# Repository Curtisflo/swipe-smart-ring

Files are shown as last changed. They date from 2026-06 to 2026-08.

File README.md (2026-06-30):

# Swipe Smart Ring — Ring PCB

The main board for a BLE smart ring with IMU-based gesture input and capacitive
touch. This repo contains the **ring board** KiCad project: PCB layout,
schematic, and the custom footprints used by both.

**Status:** prototype, not yet fabricated or tested. Routed and verified in
KiCad 9 — **DRC clean: 0 errors, 0 warnings, 0 unconnected nets.**

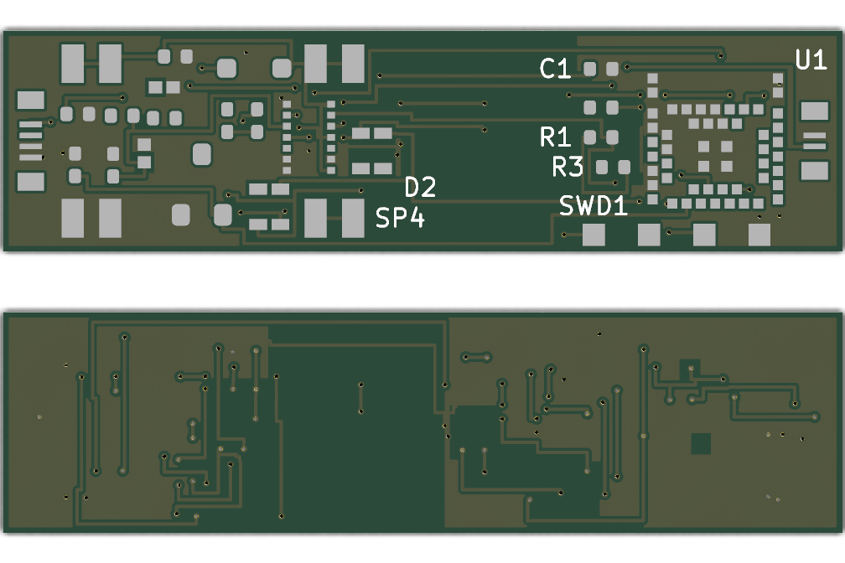
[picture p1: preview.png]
Ring board, top and bottom


It's small — the board outline is **38 × 10 mm** (about the footprint of a
stick of gum).

The board isn't meant to stay flat. The middle 8 mm is a **flex** section: the
rigid signet and BLE ends fold relative to each other there, so the board follows
the curve of the finger inside the housing. In the housing the BLE end sits
**115°** around the ring from the signet, and the rigid ends stay flat — so the
8 mm flex takes that whole ~115° bend (about a 4 mm radius, well inside the
material's 0.6 mm minimum).

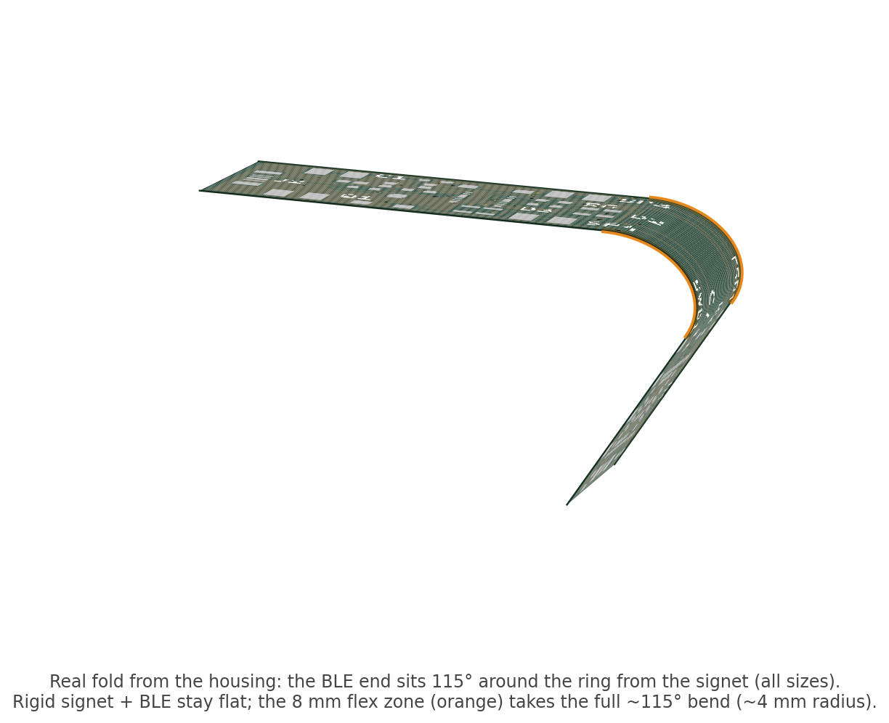
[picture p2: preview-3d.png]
Rigid-flex bend at the flex zone


A note on the rigid-flex: the flex zone is captured here as **design intent** —
the layout is zoned signet (18 mm) / flex (8 mm) / BLE (12 mm) along the board's
length, with the bend taken by the middle 8 mm. The `ring.kicad_pcb` itself is a
flat 2-layer prototype; the actual rigid-flex **stackup and coverlay callouts are
left to the fabricator**.

## What this is

A 2-layer **rigid-flex** board that wraps around a finger. It carries a Nordic
nRF52832 BLE SoC, a 6-axis IMU with built-in capacitive (Qvar) touch sensing, a
haptic motor driver, indicator LEDs, and the spring contacts / connectors that
mate with the ring housing.

The board is split into three zones along its length:

```
[ signet  18mm rigid ] —— [ flex 8mm ] —— [ BLE 12mm rigid ]
  battery + motor +                          ANNA-B112 module +
  LED arc + drivers                          antenna keepout + SWD
```

- **Signet** (rigid): battery and motor spring contacts, the two bicolor
  indicator LEDs (light-pipe aligned), the motor MOSFET and flyback diode, and
  the electrode-harness connector.
- **Flex**: the bend region that lets the rigid ends curve around the finger.
- **BLE** (rigid): the ANNA-B112 module with an antenna keepout, plus the SWD
  programming pads and the pogo-harness connector.

## Key components

| Ref | Part | Function |
|-----|---|---|
| U1  | u-blox **ANNA-B112** (nRF52832) | BLE SoC module, pre-certified, integrated antenna |
| U2  | ST **LSM6DSV16X** | 6-axis IMU + **Qvar** capacitive touch, LGA-14 |
| Q1  | Infineon IRLML6344 | N-ch MOSFET, haptic motor low-side drive |
| D1  | Vishay BAT54W | Schottky motor flyback clamp |
| D2, D3 | American Bright BL-HG0E136J | Bicolor indicator LEDs |
| ESD1/2 | ST ESDALCL5-1BM2 | ESD protection on the Qvar electrode lines |
| J1  | Molex 5034800240 | 2-pin FPC — pogo/charge harness (VBUS, GND) |
| J2  | Molex 5034800440 | 4-pin FPC — electrode harness (Qvar×2, GND×2) |
| SP1–SP4 | KYOCERA AVX 70-9155 | Spring contacts — battery (×2) and motor (×2) |

Full line-item list (passives, MPNs, prices) in [`bom.csv`](bom.csv). The
battery (Seiko MS920SE coin cell) and haptic motor are off-board — they sit in
the housing and contact the spring pads — and are listed at the end of the BOM.

## Design notes

- **No LDO.** VDD = VBAT throughout — the nRF52832 (1.7–3.6 V) runs directly
  off the coin cell (Seiko MS920SE, ~2.0–3.1 V).
- **Motor** runs off the battery rail directly, switched by Q1.
- **Qvar touch** uses the IMU's analog-front-end inputs through 500 Ω series
  resistors, with ESD diodes at the connector.
- **Charging** is resistor-limited from a 5 V pogo input (R3 = 2.2 kΩ →
  ~0.86 mA into the MS920).
- **Layers, not vias.** The fine-pitch parts (ANNA's inner pads, the LSM6DSV16X)
  are fanned out on 2 layers rather than escalating to 4-layer / via-in-pad.
  Vias are 0.3 mm (0.15 mm drill) — standard fab capability, sized so the
  LSM6DSV16X's 0.5 mm-pitch escapes clear the 0.127 mm rule.

The full product also includes a pogo charge-contact board, a Qvar electrode
flex, and a USB-C dock — those are not part of this repo.

## Opening it

Built with **KiCad 9**. Clone and open `ring.kicad_pro`, or open
`ring.kicad_pcb` / `ring.kicad_sch` directly. Footprints are embedded in the
board, and the `custom.pretty` library is included for editing.

- `ring.kicad_pcb` — routed PCB layout
- `ring.kicad_sch` — schematic
- `ring.kicad_pro` — KiCad project
- `custom.pretty/` — custom footprints
- `bom.csv` — bill of materials for this board
- `ring-schematic.pdf` — schematic as a PDF (no KiCad needed)
- `preview.png` — rendered board, top and bottom (KiCad 9, 38 × 10 mm)
- `preview-3d.png` — 3D view of the rigid-flex fold at the flex zone
- `fab/` — Gerbers and Excellon drill files (KiCad 9 export), ready to order

## License

MIT — see [LICENSE](LICENSE).

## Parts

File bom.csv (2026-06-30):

Reference | Function | MPN | Manufacturer | Package | Price_qty1 | DigiKey_Stock | Mouser_Stock | Status | Notes
C1 | Decoupling | GRM155R61A104KA01D | Murata | 0402 100nF | $0.10 | 1230000 |  | confirmed | LSM6DSV16X Vdd
C2 | Decoupling | GRM155R61A104KA01D | Murata | 0402 100nF | $0.10 | 1230000 |  | confirmed | LSM6DSV16X Vdd_IO
C7 | Qvar filter | GRM1555C1H111JA01D | Murata | 0402 110pF | ~$0.10 |  |  | confirmed | Qvar electrode 1
C8 | Qvar filter | GRM1555C1H111JA01D | Murata | 0402 110pF | ~$0.10 |  |  | confirmed | Qvar electrode 2
D1 | Motor flyback diode | BAT54W-E3-08 | Vishay | SOD-123 | $0.14 | 22300 |  | confirmed | Clamps motor back-EMF to VDD. NOT reverse polarity protection.
D2 | Status LED 1 | BL-HG0E136J-TRB | American Bright | 0605 1.6x1.5x0.55mm | $0.05 | 152905 |  | confirmed | Bi-color red (Vf=2.0V) + yellow-green (Vf=2.2V). Signet indicator.
D3 | Status LED 2 | BL-HG0E136J-TRB | American Bright | 0605 1.6x1.5x0.55mm | $0.05 | 152905 |  | confirmed | Same. (Reduced from 4 LEDs to 2 — see design-notes.)
ESD1 | Qvar ESD protection | ESDALCL5-1BM2 | STMicroelectronics | SOD-882 1.0x0.6mm | $0.39 | 448 | 7633 | confirmed — optional for proto | Protects Qvar1 electrode pin from ESD via skin contact.
ESD2 | Qvar ESD protection | ESDALCL5-1BM2 | STMicroelectronics | SOD-882 1.0x0.6mm | $0.39 | 448 | 7633 | confirmed — optional for proto | Protects Qvar2 electrode pin.
J1 | FPC connector | 5034800240 | Molex | FPC 0.5mm 2-pin | — |  |  | confirmed | 2-pin FPC — pogo/charge harness (VBUS, GND)
J2 | FPC connector | 5034800440 | Molex | FPC 0.5mm 4-pin | — |  |  | confirmed | 4-pin FPC — electrode harness (QVAR1_RAW, QVAR2_RAW, GND, GND)
Q1 | Motor MOSFET | IRLML6344TRPBF | Infineon | SOT-23 | $0.54 | 171800 |  | confirmed | Vgs_th 1.1V. Driven from VBAT GPIO (~3.0V). Motor on battery rail. Note: Vgs at 3.0V is above threshold — confirmed OK.
R1 | I2C pull-up | RC0402FR-0710KL | Yageo | 0402 10k | $0.02 |  |  | confirmed | SDA — 10k per LSM6DSV16X datasheet
R2 | I2C pull-up | RC0402FR-0710KL | Yageo | 0402 10k | $0.02 |  |  | confirmed | SCL
R3 | Charge current limit | RC0402FR-072K2L | Yageo | 0402 2.2k | $0.02 |  |  | redesign needed | MS920 charge resistor. From VBUS (5V) through R3 to battery. I_charge = (5V - 3.1V) / 2.2k ≈ 0.86mA (~0.08C). See Seiko datasheet for recommended charge method.
R4 | Qvar series | RC0402FR-07499RL | Yageo | 0402 500R | $0.02 |  |  | confirmed | Qvar electrode 1 series resistor (499R = nearest E96 1% to 500R)
R5 | Qvar series | RC0402FR-07499RL | Yageo | 0402 500R | $0.02 |  |  | confirmed | Qvar electrode 2 series resistor (499R = nearest E96 1% to 500R)
R6 | LED current limit | RC0402FR-07100RL | Yageo | 0402 100R | $0.02 |  |  | confirmed | Red channel (2 LEDs ganged parallel at 5mA each = 10mA). At 3.0V VBAT: (3.0-2.0)/0.010=100Ω.
R7 | LED current limit | RC0402FR-0782RL | Yageo | 0402 82R | $0.02 |  |  | confirmed | Yellow-green channel (2 LEDs ganged). At 3.0V: (3.0-2.2)/0.010=80Ω, use 82Ω E12. May dim below 2.8V battery.
R8 | Q1 gate pull-down | RC0402FR-07100KL | Yageo | 0402 100k | $0.02 |  |  | confirmed | Holds Q1 gate low while HAPTIC_EN is hi-Z (boot/reset/firmware crash) — prevents an uncommanded motor run on a floating gate.
SP1 | Battery + spring contact | 709155001610004 | KYOCERA AVX | 2.70x1.75x1.0mm | $0.15 | 6331 |  | confirmed | BeCu leaf spring, gold/nickel plated. Presses against MS920SE + solder tab. 1.0mm nominal height (0.75-1.25mm range). SMD reflow.
SP2 | Battery - spring contact | 709155001610004 | KYOCERA AVX | 2.70x1.75x1.0mm | $0.15 | 6331 |  | confirmed | Same part as SP1. Presses against MS920SE - solder tab.
SP3 | Motor VBAT spring contact | 709155001610004 | KYOCERA AVX | 2.70x1.75x1.0mm | $0.15 | 6331 |  | confirmed | Same part as SP1. Motor + wire presses against spring when signet housing closes.
SP4 | Motor MOTOR_N spring contact | 709155001610004 | KYOCERA AVX | 2.70x1.75x1.0mm | $0.15 | 6331 |  | confirmed | Same part as SP1. Motor - wire presses against spring when signet housing closes.
U1 | BLE module | ANNA-B112-02B | u-blox | SMD-52 6.5x6.5x1.2mm | $5.25 | 464 | 5279 | confirmed | nRF52832. Chip antenna + tuning strip (~6.5mm). Tiny no-GND zone. Proven at ring-scale PCBs (250m range on 46x8mm board). FCC/IC/CE certified. Replaces ISP1807.
U2 | IMU + Qvar touch | LSM6DSV16X | STMicroelectronics | LGA-14 2.5x3x0.83mm | ~$4.10 | 0 | 19900 on order | confirmed — stock risk | Out of stock everywhere. Mouser has 19.9k on order. No alternative for Qvar+IMU combo.
BT1 | Battery | MS920SE-FL27E | Seiko Instruments | 9.5mm dia x 2.1mm coin | $2.63 | 9942 |  | confirmed | 11mAh 3.0V rechargeable Li-MnO2. SMD solder tab. ~3.5 day battery life at 0.13mA avg. Charge via resistor-limited current from VBUS. Fits ring envelope trivially (9.5mm dia).
M1 | Haptic motor | VCLP0820B004L | Vybronics | 8mm dia x 2.0mm | $3.09 | 3994 |  | confirmed | Low current variant: 35mA max rated, 50mA starting. 0.25Grms vibration. Wire leads press against SP3/SP4 spring contacts when signet housing closes. Self-adhesive tape included.

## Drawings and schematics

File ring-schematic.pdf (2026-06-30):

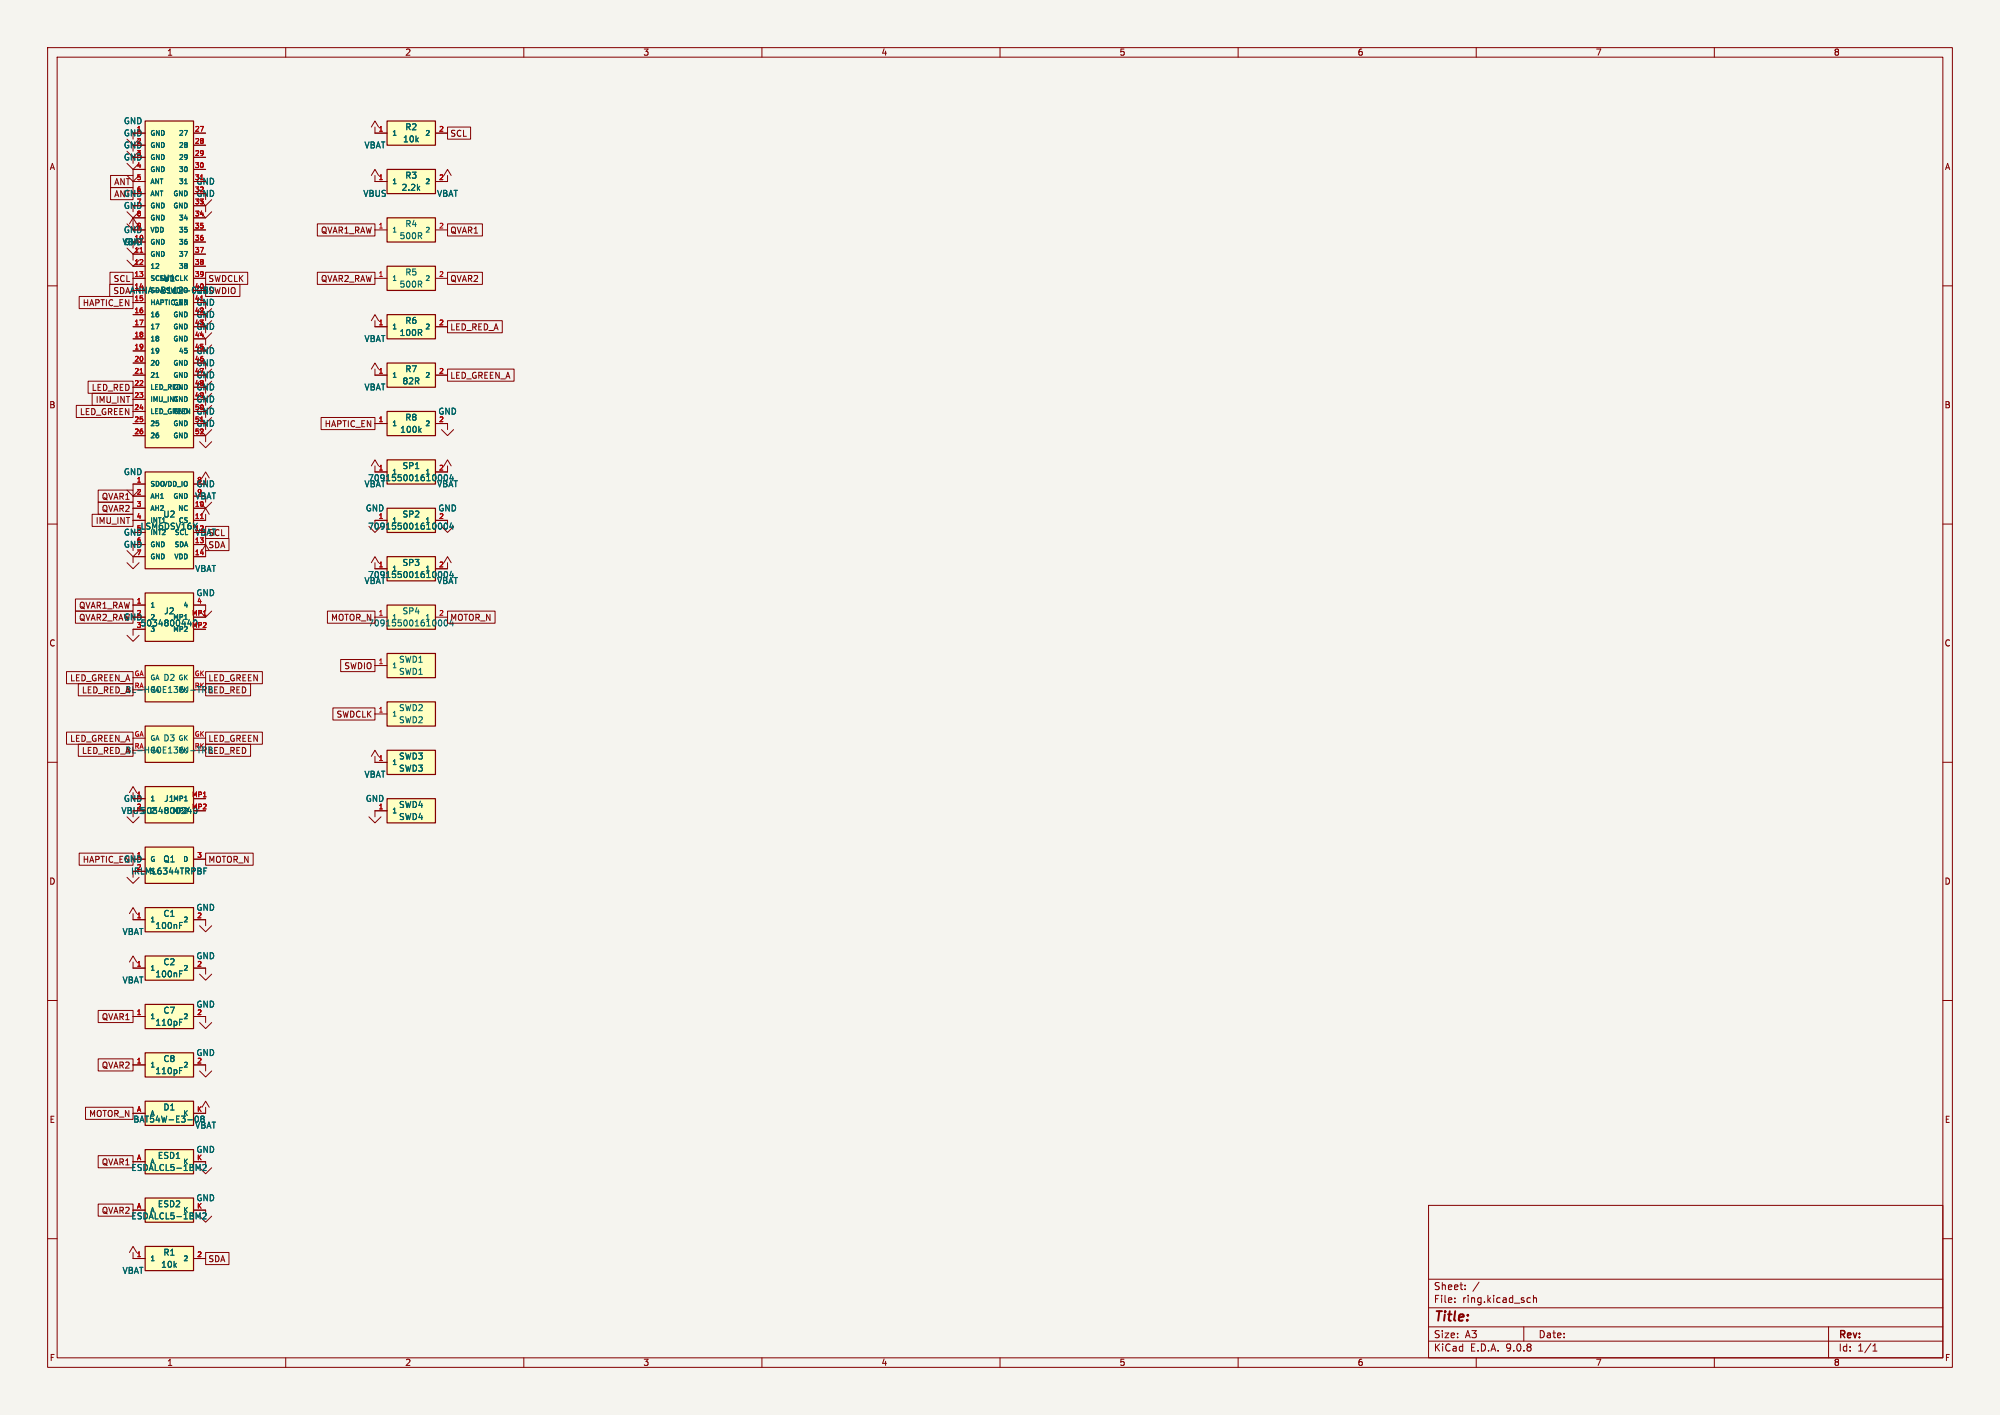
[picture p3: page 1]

Id: 1/1 Title: File: ring.kicad_sch Sheet: /

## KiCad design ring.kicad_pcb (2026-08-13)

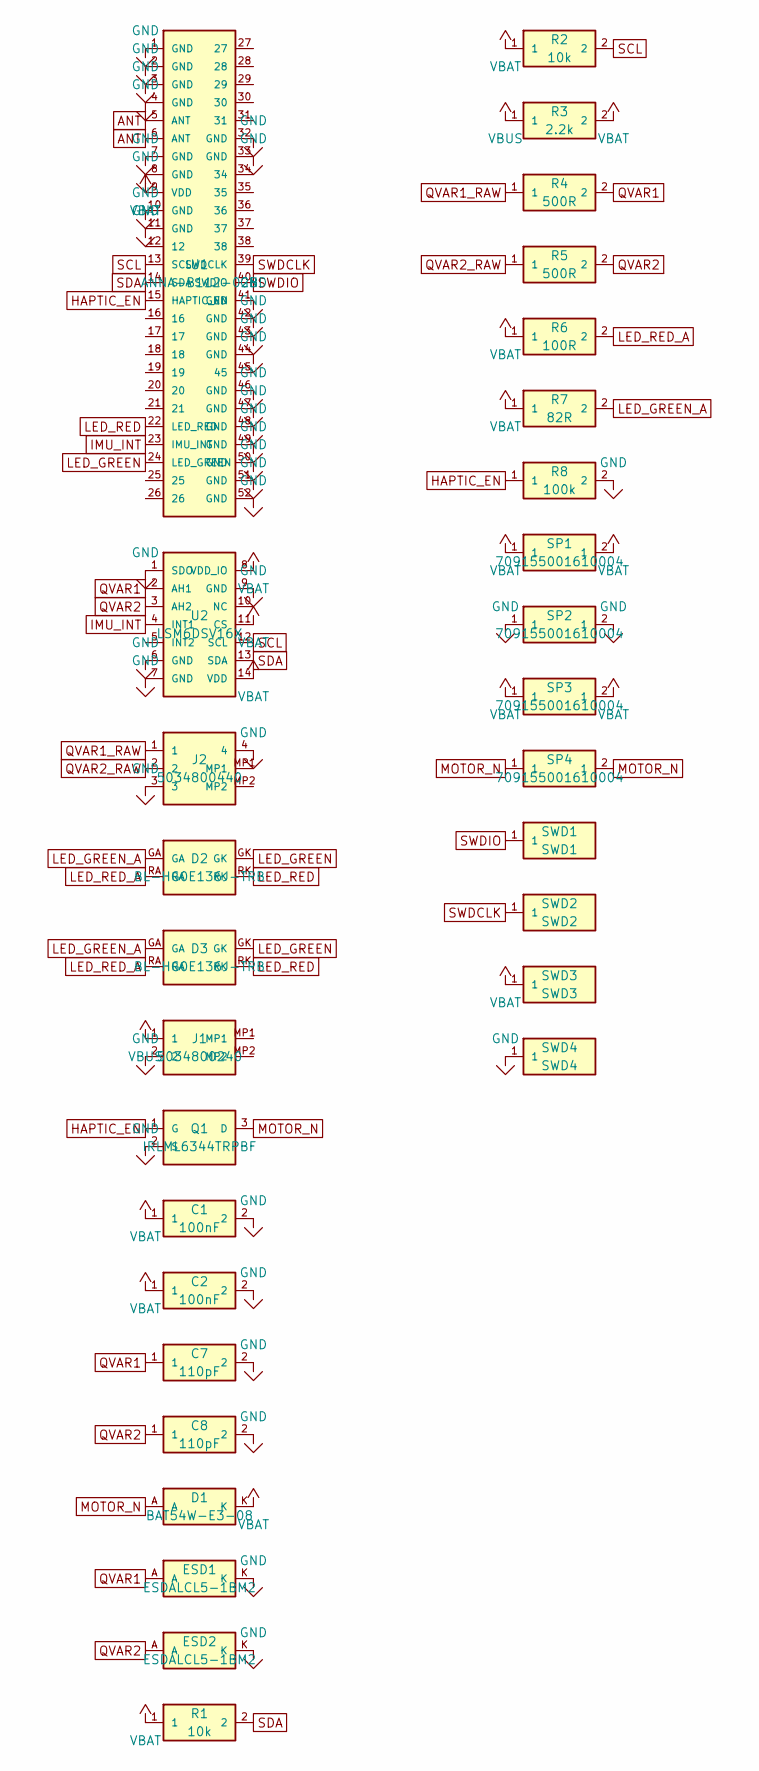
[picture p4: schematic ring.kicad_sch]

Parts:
C1, C2: 100nF; R_0402_1005Metric
C7, C8: 110pF; R_0402_1005Metric
D1: BAT54W-E3-08; D_SOD-123
D2, D3: BL-HG0E136J-TRB; LED_0605_BiColor
ESD1, ESD2: ESDALCL5-1BM2; D_SOD-882
J1: 5034800240; Molex_503480_2pin
J2: 5034800440; Molex_503480_4pin
Q1: IRLML6344TRPBF; SOT-23
R1, R2: 10k; R_0402_1005Metric
R3: 2.2k; R_0402_1005Metric
R4, R5: 500R; R_0402_1005Metric
R6: 100R; R_0402_1005Metric
R7: 82R; R_0402_1005Metric
R8: 100k; R_0402_1005Metric
SP1, SP2, SP3, SP4: 709155001610004; AVX_9155_Battery_Contact
SWD1: SWD1; Pad_1.0x1.0mm
SWD2: SWD2; Pad_1.0x1.0mm
SWD3: SWD3; Pad_1.0x1.0mm
SWD4: SWD4; Pad_1.0x1.0mm
U1: ANNA-B112-02B; ANNA-B112
U2: LSM6DSV16X; LGA-14_2.5x3mm_P0.5mm_LSM6DSV16X

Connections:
ANT: U1.5 (ANT), U1.6 (ANT)
GND: C1.2, C2.2, C7.2, C8.2, ESD1.K, ESD2.K, J1.2, J2.3, J2.4, Q1.2 (S), R8.2, SP2.1, SP2.2, SWD4.1, U1.1 (GND), U1.2 (GND), U1.3 (GND), U1.4 (GND), U1.7 (GND), U1.8 (GND), U1.10 (GND), U1.11 (GND), U1.32 (GND), U1.33 (GND), U1.41 (GND), U1.42 (GND), U1.43 (GND), U1.44 (GND), U1.46 (GND), U1.47 (GND), U1.48 (GND), U1.49 (GND), U1.50 (GND), U1.51 (GND), U1.52 (GND), U2.1 (SDO), U2.6 (GND), U2.7 (GND), U2.9 (GND)
HAPTIC_EN: Q1.1 (G), R8.1, U1.15 (HAPTIC_EN)
IMU_INT: U1.23 (IMU_INT), U2.4 (INT1)
LED_GREEN: D2.GK, D3.GK, U1.24 (LED_GREEN)
LED_GREEN_A: D2.GA, D3.GA, R7.2
LED_RED: D2.RK, D3.RK, U1.22 (LED_RED)
LED_RED_A: D2.RA, D3.RA, R6.2
MOTOR_N: D1.A, Q1.3 (D), SP4.1, SP4.2
QVAR1: C7.1, ESD1.A, R4.2, U2.2 (AH1)
QVAR1_RAW: J2.1, R4.1
QVAR2: C8.1, ESD2.A, R5.2, U2.3 (AH2)
QVAR2_RAW: J2.2, R5.1
SCL: R2.2, U1.13 (SCL), U2.12 (SCL)
SDA: R1.2, U1.14 (SDA), U2.13 (SDA)
SWDCLK: SWD2.1, U1.39 (SWDCLK)
SWDIO: SWD1.1, U1.40 (SWDIO)
VBAT: C1.1, C2.1, D1.K, R1.1, R2.1, R3.2, R6.1, R7.1, SP1.1, SP1.2, SP3.1, SP3.2, SWD3.1, U1.9 (VDD), U2.8 (VDD_IO), U2.11 (CS), U2.14 (VDD)
VBUS: J1.1, R3.1

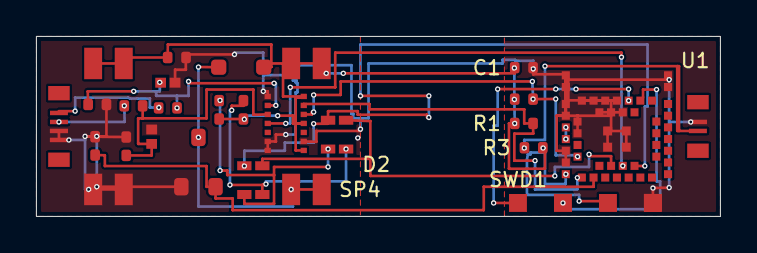
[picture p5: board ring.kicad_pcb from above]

Board: 2 copper layers, 38.0 x 10.0 mm, 30 parts (0 on the bottom side), 19 nets.

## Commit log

2026-06-28 Add Swipe smart ring board: KiCad PCB, schematic, footprints
    2-layer rigid-flex ring board (ANNA-B112 BLE + LSM6DSV16X IMU/Qvar).
    Includes routed layout, schematic, custom footprints, rendered preview,
    and a schematic PDF.
    [ring.kicad_pcb, ring.kicad_sch]
2026-06-29 Add ring-board BOM and a top+bottom board preview
    Filter the master product BOM down to parts on/mated to this board.
    Replace the top-only render with a labelled top+bottom composite.
    [bom.csv]
2026-06-29 Dimension the board preview (38 x 10 mm)
    Draw dimension lines on the TOP view: width line under the board, height
    line on its side, both keyed to the Edge.Cuts outline.
2026-06-29 Add 3D viz of the rigid-flex fold
    Map the top render onto a bent surface: rigid signet + BLE ends flat, the
    8 mm flex zone hinging so the board follows the finger. Clarify in the
    README that the board is meant to fold, not stay flat.
2026-06-29 Use the real 115 deg fold from the housing
    Pull ble_angle (115 deg, fixed across all ring sizes) from the housing
    derive() pipeline instead of the illustrative 75 deg, and re-render. Note
    the flex radius (~4 mm) clears the 0.6 mm minimum.
2026-06-29 Mark flex zone in board; fill BOM MPNs; honest status notes
    - Draw the flex-zone boundary + fab note on User.Drawings in ring.kicad_pcb
    - Fill the 9 TBD passive MPNs (Yageo RC0402 / Murata GRM15)
    - README: prototype status, accurate DRC (0 errors; 2 minor VBAT warnings),
    and note that the rigid-flex stackup is left to the fabricator
    [bom.csv, ring.kicad_pcb]
2026-06-29 Normalize ring board to DRC-clean
    Drop a redundant near-stacked VBAT via (hole_to_hole) and a dangling B.Cu
    stub + the via it orphaned (track_dangling), via the khalkeus normalize
    pass. Connectivity unchanged; KiCad DRC now 0 errors / 0 warnings.
    Regenerate the previews and update the status note.
    [ring.kicad_pcb]
2026-06-29 Add fabrication Gerbers and drill files for ring board
    [ring-B_Courtyard.gbr, ring-B_Cu.gbl, ring-B_Fabrication.gbr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]
2026-06-29 Document fab/ Gerber package in README
2026-06-30 Fix bi-color LED miswire; re-solve clean (0 DRC / 0 parity)
    The LEDs (D2/D3) were miswired: the net-to-pad assignment was scrambled,
    so the green die had both terminals on VBAT (dead) and the red die was
    GPIO-to-GPIO with no current limit. The board was DRC-clean, so it
    looked fine -- but it was electrically broken, and the schematic was 111
    parity-issues out of sync with the PCB.
    - corrected LED net mapping (re-solved on the fixed netlist)
    - schematic now matches the PCB exactly: 0 schematic-parity issues
    (symbol pin numbers = footprint pad names; global, slash-free labels)
    - vias 0.4 -> 0.3mm (0.15mm drill) so the LSM6DSV16X's 0.5mm-pitch
    escapes clear the 0.127mm rule -> 0 DRC
    - bom: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
    [bom.csv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]
2026-07-02 Trim fab/ to the standard manufacturing gerber set
    Drop empty documentation layers (adhesive, courtyard, fabrication,
    margin, user comments/drawings/eco) that carried no content for this
    2-layer board, and regenerate the remaining gerbers fresh from the
    same board data via the project's standard export recipe. Re-verified
    DRC clean (0/0/0) — board itself is unchanged.
    [ring-B_Courtyard.gbr, ring-B_Cu.gbl, ring-B_Fabrication.gbr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]
2026-07-02 Fix R1 silkscreen label overlapping R2/R3
    R1's reference text sat 0.01mm into both neighbors' bounding boxes on
    F.Silkscreen -- a hairline overlap KiCad's DRC never flagged (board
    was, and still is, DRC clean), but visible as touching/crowded text
    in the rendered preview. Repositioned the label, regenerated fab/
    gerbers and preview.png. DRC/parity still 0/0/0.
    [ring-B_Cu.gbl, ring-B_Mask.gbs, ring-B_Paste.gbp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]
2026-07-02 Move C1/R1/R2/R3/SWD1 silkscreen off the trace bus
    Not a DRC violation (soldermask covers the traces) but read as messy
    in the render -- these five labels were crossing 1-10 copper trace
    segments each near U1's I2C/GPIO fanout. Repositioned to minimize
    crossings (four to zero, R3 10->1, R1 floors at 1 -- the bus is too
    dense there for any offset to clear it). Regenerated fab/ and
    preview.png. DRC/parity still 0/0/0.
    [ring-B_Cu.gbl, ring-B_Mask.gbs, ring-B_Paste.gbp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]
2026-08-12 Sync board after router C-A* port and hole-to-hole fix
    The monorepo router now runs its via-penalty and corridor costs in the
    C accelerator; re-routing under C tie-breaking removed all three
    negative-annular via-in-pads on U2, cut total trace 576 -> 502 mm
    (83 -> 81 vias), and a new net-independent drill-spacing guard
    relocated one GND stitch via. Verified on this repo's pair:
    kicad-cli DRC + schematic parity 0 errors / 0 warnings / 0 unconnected.
    Gerber + drill set and the top/bottom preview regenerated;
    preview-3d (the fold illustration, geometry unchanged) kept as-is.
    [ring-B_Cu.gbl, ring-B_Mask.gbs, ring-B_Paste.gbp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]
2026-08-12 Sync board after via-in-pad guard hardening
    The monorepo router now enforces a commit-time annular floor for
    terminating vias (rejects below-floor via-in-pad before commit, loud
    actionable failures) and re-routed the ring under it. This board keeps
    its 23 adequate-annular via-in-pads (all >= +0.075 mm ring; the
    poking-past class is extinct) with zero negative-annular and zero
    hole-to-hole findings. Verified on this repo's pair: kicad-cli DRC +
    schematic parity 0 errors / 0 warnings / 0 unconnected. Gerber + drill
    set and top/bottom preview regenerated.
    [ring-B_Cu.gbl, ring-B_Mask.gbs, ring-B_Paste.gbp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]
2026-08-13 Move silkscreen reference text off via barrels
    The monorepo's silk placer now treats vias as obstacles (its obstacle
    model was pads-only); U1/SP3/R2 references moved off the via barrels
    they were printed over. Copper is unchanged from the previous commit —
    this is a silkscreen-only revision. Verified: kicad-cli DRC + schematic
    parity 0 errors / 0 warnings / 0 unconnected. Gerbers, drill set, and
    preview regenerated.
    [ring-B_Cu.gbl, ring-B_Mask.gbs, ring-B_Paste.gbp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]
